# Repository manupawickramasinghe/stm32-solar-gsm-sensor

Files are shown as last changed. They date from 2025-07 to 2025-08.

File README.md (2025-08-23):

# stm32-solar-gsm-sensor
Firmware and hardware guide for an open-source, solar-powered agricultural sensor system based on the STM32 "Blue Pill" and a SIM800L GSM module.

This project is designed for remote environmental monitoring. It periodically reads data from multiple sensors based on DIP switch configuration, aggregates the data, and sends a summary report via SMS to a predefined list of phone numbers. It is optimized for low-power operation, making it suitable for solar or battery-powered deployments.

## Features
- **Multi-Sensor Support with DIP Switch Selection**: 
  - DHT11 temperature and humidity sensor
  - DS18B20 waterproof temperature sensor
  - FC-28 soil moisture sensor
  - MQ2 gas sensor
  - 4-position DIP switch for enabling/disabling individual sensors

- **GSM Connectivity**: Uses a SIM800L module to connect to the cellular network for sending and receiving SMS messages.

- **Periodic Data Reporting**: The device wakes up every 5 minutes to take sensor readings from enabled sensors only.

- **Dynamic SMS Content**: SMS reports include only data from sensors that are enabled via DIP switches. If no sensors are enabled, only timestamp is sent.

- **Averaged Data SMS**: After a set number of readings (e.g., 12 readings over 60 minutes), it calculates the average sensor values and sends a consolidated report via SMS.

- **Multi-Recipient SMS**: Sends the report to a configurable list of multiple phone numbers.

- **Network Timestamp**: Fetches the current date and time from the cellular network and includes it in every SMS report for accurate logging.

- **Persistent Counter**: Uses Flash memory emulation (since the STM32F103C8T6 does not have built-in EEPROM) to save its reading counter, ensuring it can resume its cycle even after a power loss or reset.

- **Remote Control via SMS**: Comprehensive SMS command system for remote configuration and monitoring.

## Hardware Requirements
- **Microcontroller**: STM32F103C8T6 "Blue Pill" board.

- **GSM Module**: SIM800L module (ensure it comes with a spring antenna and a valid 2G SIM card).

- **DIP Switch**: 4-position DIP switch for sensor selection.

- **Sensors**:
  - DHT11 Temperature and Humidity Sensor (Pin: PB1)
  - DS18B20 Waterproof Temperature Sensor (Pin: PB0) with 4.7kΩ pull-up resistor
  - FC-28 Soil Moisture Sensor (Analog Pin: PA1)
  - MQ2 Gas Sensor (Analog Pin: PA4)

- **Pin Assignments for DIP Switches**:
  - DIP Switch 1 (DHT11): PC13
  - DIP Switch 2 (DS18B20): PC14  
  - DIP Switch 3 (Soil Moisture): PC15
  - DIP Switch 4 (MQ2 Gas): PB12

- **Programmer**: FTDI FT232RL USB-to-Serial adapter for flashing the firmware.

- **Power Supply**:
  - A stable power source for the SIM800L is critical. A 3.7V LiPo battery or a dedicated buck converter capable of supplying at least 2A peak current is highly recommended. Powering the SIM800L directly from the Blue Pill's 3.3V pin will cause instability.

## Software & Setup (Arduino IDE)
This project is built using the Arduino IDE with the official STM32 core.

1. **Install Arduino IDE**
   If you don't have it, download and install the latest version of the Arduino IDE.

2. **Install STM32 Board Support**
   Open the Arduino IDE.

   Go to `File > Preferences`.

   In the "Additional boards manager URLs" field, paste the following URL:

   ```
   https://github.com/stm32duino/BoardManagerFiles/raw/main/package_stmicroelectronics_index.json
   ```

   Go to `Tools > Board > Boards Manager...`.

   Search for "STM32 MCU based boards" and install the package by STMicroelectronics.

3. **Install Required Libraries**
   You need to install three libraries for the sensors.

   Go to `Tools > Manage Libraries...`.

   Search for and install each of the following libraries:

   - DHT sensor library by Adafruit

   - OneWire by Paul Stoffregen

   - DallasTemperature by Miles Burton

4. **Configure the Code**
   Open the `.ino` sketch file in the Arduino IDE.

   Modify the `phoneNumbers` array to include the recipient phone numbers you want to send the SMS reports to. Make sure to use the international format (e.g., +94...).

   ```cpp
   String phoneNumbers[] = {"+94719593248", "+94719751003"};
   ```

## Flashing the Firmware (Manual Upload)
Since this project uses an FTDI adapter, you cannot use the standard "Upload" button in the Arduino IDE. You must compile the binary and flash it manually using a command-line tool.

### Step 1: Compile and Export the Binary
In the Arduino IDE, select the correct board settings:

- `Tools > Board: "STM32 MCU based boards" > "Generic STM32F1 series"`

- `Tools > Board part number: "Bluepill F103C8"`

- `Tools > Upload method: "STM32CubeProgrammer (Serial)"`

Go to `Sketch > Export compiled Binary`. This will compile your code and create a `.hex` and `.bin` file in the sketch folder.

### Step 2: Install stm32flash
This is a lightweight, reliable tool for flashing STM32 devices via UART.

Open a terminal on your Linux machine and run:

```bash
sudo apt update
sudo apt install stm32flash
```

### Step 3: Set Up Hardware for Flashing
This is the most critical part. You must put the STM32 into its hardware bootloader mode.

- **Set Jumpers**:

  - Set the `BOOT0` jumper to the '1' position (HIGH).

  - Set the `BOOT1` jumper to the '0' position (LOW).

- **Wire the FTDI Adapter**:

  - FTDI GND -> STM32 GND

  - FTDI TX -> STM32 PA10 (RX1)

  - FTDI RX -> STM32 PA9 (TX1)

- **Connect and Reset**: Connect the FTDI adapter to your computer. Now, press the RESET button on the Blue Pill board. The board is now waiting for programming commands.

### Step 4: Fix Serial Port Permissions (One-Time Setup)
On Linux, your user needs permission to access serial devices.

Add your user to the dialout group:

```bash
sudo usermod -a -G dialout $USER
```

IMPORTANT: For this change to take effect, you must log out and log back in or reboot your computer.

### Step 5: Flash the Firmware
Open a terminal and navigate to your Arduino sketch directory where the `.bin` file was exported.

Run the `stm32flash` command:

```bash
stm32flash -b 115200 -w YourSketchName.ino.bin -v -g 0x0 /dev/ttyUSB0
```

- `-b 115200`: Sets the baud rate for reliable communication.

- `-w YourSketchName.ino.bin`: Specifies the binary file to write.

- `-v`: Verifies the flash after writing.

- `-g 0x0`: Starts execution from the beginning of the flash memory after programming.

- `/dev/ttyUSB0`: The serial port of your FTDI adapter.

### Step 6: Run the Application
Disconnect the power.

Set the `BOOT0` jumper back to the '0' position.

Reconnect power or press the RESET button.

The board will now boot into your application. You can open the Arduino IDE's Serial Monitor at 9600 baud to see the debug output.

## Code Explanation
- **Configuration (`#define`)**: All hardware pins, timing delays, and operational thresholds are defined at the top of the file for easy configuration.

- **setup()**: This function runs once on startup. It initializes the serial ports for debugging, starts the DHT and DS18B20 sensors, and crucially, initializes the SIM800L module with a series of AT commands to prepare it for sending SMS. It also reads the last known `smsCounter` value from the EEPROM.

- **loop()**: This is the main operational cycle.

  - It first ensures the GSM module is initialized and ready.

  - It reads the current temperature and humidity from both sensors.

  - The readings are added to summing variables (`dhtHumSum`, `dhtTempSum`, etc.).

  - A counter (`smsCounter`) is incremented and saved to the EEPROM.

  - It checks if `smsCounter` has reached the `SMS_SEND_THRESHOLD` (e.g., 12).

  - If the threshold is met, it calculates the averages, fetches a network timestamp, formats the SMS message, and sends it to all phone numbers in the `phoneNumbers` array.

  - Finally, it resets the summing variables and the `smsCounter` back to zero and waits for 5 minutes (`MAIN_LOOP_CYCLE_DELAY`) before starting the next cycle.

- **GSM Helper Functions**: Functions like `sendSMS()`, `getGsmTimestamp()`, and `handleSim800lInput()` abstract the complexity of communicating with the SIM800L module.

## DIP Switch Configuration
The system uses a 5-position DIP switch to enable/disable individual sensors and MQTT publishing:

- **DIP Switch 1 (PC13)**: DHT11 Temperature & Humidity Sensor
- **DIP Switch 2 (PC14)**: DS18B20 Waterproof Temperature Sensor  
- **DIP Switch 3 (PC15)**: FC-28 Soil Moisture Sensor
- **DIP Switch 4 (PB12)**: MQ2 Gas Sensor
- **DIP Switch 5 (PB13)**: MQTT Publishing to test.mosquitto.org

**Switch Logic**: 
- Switch DOWN (pulled to ground) = Feature ENABLED
- Switch UP (pulled high) = Feature DISABLED

**Important**: The system reads DIP switches only during startup/boot. To change sensor or MQTT configuration, modify the DIP switches and restart the system. Only enabled sensors are read and included in SMS reports. If MQTT is enabled, data will be published to test.mosquitto.org after SMS transmission.

## SMS Commands
The system supports remote configuration and monitoring via SMS commands. Send these commands to the SIM card phone number:

### Configuration Commands
- **`NUMSETA +1234567890`**: Set phone number A
- **`NUMSETB +1234567890`**: Set phone number B  
- **`NUMSETC +1234567890`**: Set phone number C
- **`SETID 12345`**: Set customer ID (max 9 characters)

### Status Commands
- **`STATUS`**: Get current configuration, enabled sensors, and MQTT status
- **`TEST`**: Simple connectivity test
- **`SENSOR`**: Get current real-time sensor readings from enabled sensors
- **`MQTT`**: Test MQTT publishing (if MQTT enabled)

### Example SMS Responses
- **STATUS**: `ID:12345 A:+94719593248 B:+94719751003 C:+94768378406 Sensors: DHT DS18B20 SOIL MQTT`
- **SENSOR**: `ID:12345 Current: DHT H:65.2% T:28.4C; DS18B20:27.8C; Soil:45.3%;`
- **MQTT**: `ID:12345 MQTT test publish initiated`

## MQTT Integration
When the MQTT DIP switch is enabled (DIP Switch 5), the system will:

1. **Automatic Publishing**: After sending SMS data, automatically publish sensor data to MQTT
2. **MQTT Broker**: Uses test.mosquitto.org on port 1883 (public test broker)
3. **Topic Structure**: `sensors/stm32/{customer_id}`
4. **Data Format**: JSON payload with sensor readings and metadata
5. **Manual Testing**: Use `MQTT` SMS command to test publishing

### MQTT Data Example
```json
{
  "customer_id": "FARM01",
  "timestamp": "2025-08-03 14:30:15",
  "dht_humidity": 65.2,
  "dht_temperature": 28.4,
  "ds18b20_temperature": 27.8,
  "soil_moisture": 45.3,
  "gas_level": 12.1,
  "reading_count": 12
}
```

All configurations are saved to EEPROM and persist across power cycles.

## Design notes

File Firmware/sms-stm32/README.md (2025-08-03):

# STM32 Solar GSM Sensor System

A non-blocking, state-machine-based environmental monitoring system using STM32 Blue Pill with DHT11, DS18B20 sensors, and SIM800L GSM module for remote SMS notifications and configuration.

## 🌟 Features

- **Dual Temperature Sensors**: DHT11 (humidity + temperature) and DS18B20 (precision temperature)
- **SMS Notifications**: Automatic periodic sensor data reports via SMS
- **Remote Configuration**: Change phone numbers and customer ID via SMS commands
- **Non-blocking Architecture**: Fully asynchronous operation using state machines
- **EEPROM Storage**: Persistent configuration storage
- **Timestamp Integration**: GSM network time for accurate data logging
- **Multiple Recipients**: Send data to up to 3 phone numbers simultaneously

## 📱 SMS Commands

| Command | Description | Example |
|---|---|---|
| `STATUS` | Get current configuration | `STATUS` |
| `TEST` | Test system response | `TEST` |
| `NUMSETA +1234567890` | Update phone number A | `NUMSETA +94712345678` |
| `NUMSETB +1234567890` | Update phone number B | `NUMSETB +94712345678` |
| `NUMSETC +1234567890` | Update phone number C | `NUMSETC +94712345678` |
| `SETID CUSTOMER1` | Set customer ID (max 9 chars) | `SETID FARM01` |

### Example SMS Responses
```
Send: STATUS
Receive: 2025-08-02 14:30:15 - ID:00000 A:+94719593248 B:+94719751003 C:+94768378406

Send: NUMSETB +94716223703
Receive: 2025-08-02 14:30:25 - ID:00000 NUMSETB updated to +94716223703

Send: SETID FARM01
Receive: 2025-08-02 14:30:35 - ID:FARM01 Customer ID updated to FARM01
```

## 🔧 Hardware Configuration

### Pin Connections
```
STM32 Blue Pill Connections:
├── DHT11 Sensor
│   └── Data Pin: PB1
├── DS18B20 Sensor
│   └── Data Pin: PB0 (with 4.7kΩ pull-up resistor)
├── SIM800L GSM Module
│   ├── RX: PA3 (STM32 TX → SIM800L RX)
│   ├── TX: PA2 (STM32 RX ← SIM800L TX)
│   └── Baud Rate: 9600
└── Power: 3.3V/5V (depending on module requirements)
```

### Required Components
- STM32 Blue Pill (STM32F103C8T6)
- DHT11 Temperature & Humidity Sensor
- DS18B20 Digital Temperature Sensor
- 4.7kΩ resistor (for DS18B20 pull-up)
- SIM800L GSM/GPRS Module
- SIM card with SMS capability
- Power supply (suitable for GSM module)

## 📊 System Operation

### Automatic Data Collection
- **Reading Cycle**: Every 5 minutes (300,000ms)
- **SMS Threshold**: Sends SMS after 12 readings (60 minutes of data)
- **Data Averaging**: Calculates average values over the collection period
- **Auto Reset**: Counters and averages reset after SMS transmission

### Example Sensor Data SMS
```
2025-08-02 21:10:59 - ID:FARM01 60min Avg - DHT H:65.2% T:28.5C; DS18B20 T:27.8C
```

## 🏗️ Software Architecture

### State Machine Design
The system uses multiple state machines for non-blocking operation:

#### 1. Main Sensor State Machine
```
STATE_IDLE → STATE_WAIT_DHT → STATE_READ_DHT → 
STATE_WAIT_DS18B20 → STATE_READ_DS18B20 → 
STATE_PROCESS_DATA → STATE_IDLE
```

#### 2. GSM Initialization State Machine
```
GSM_INIT_START → GSM_INIT_BOOT_DELAY → 
GSM_INIT_ECHO_OFF_WAIT → GSM_INIT_AT_TEST → 
GSM_INIT_AT_TEST_WAIT → ... → GSM_INIT_COMPLETE
```

#### 3. SMS Operation State Machine
```
SMS_IDLE → SMS_READ_WAIT → SMS_DELETE_WAIT
SMS_IDLE → SMS_SEND_CMD_WAIT → SMS_SEND_DATA_WAIT → SMS_SEND_END_WAIT
```

### Key Functions

#### Core Loop Functions
- `loop()`: Main system loop with state machine coordination
- `updateGsmInitialization()`: Non-blocking GSM module setup
- `updateSmsOperations()`: Handles SMS read/send/delete operations
- `updateSmsProcessing()`: Processes incoming SMS commands
- `handleSim800lInput()`: Manages incoming GSM module data

#### SMS Command Processing
- `extractSmsContentAndSender()`: Parses SMS content and sender info
- `parseAndExecuteSmsCommand()`: Executes SMS commands and generates responses
- `sendSMS()`: Sends SMS with timestamp to specified number

#### Configuration Management
- `loadConfigFromEEPROM()`: Loads saved configuration on startup
- `savePhoneNumberToEEPROM()`: Saves phone numbers to EEPROM
- `saveCustomerIDToEEPROM()`: Saves customer ID to EEPROM

## 💾 EEPROM Memory Map

| Address | Size | Description |
|---|---|---|
| 0 | 4 bytes | SMS Counter |
| 4-23 | 20 bytes | Phone Number A |
| 24-43 | 20 bytes | Phone Number B |
| 44-63 | 20 bytes | Phone Number C |
| 64-73 | 10 bytes | Customer ID |
| 74 | 1 byte | Initialization Flag |

## ⚙️ Configuration Parameters

### Timing Configuration
```cpp
#define MAIN_LOOP_CYCLE_DELAY 300000    // 5 minutes between readings
#define SMS_SEND_THRESHOLD 12           // Send SMS after 12 readings
#define DHT_READ_PRE_DELAY 2000         // 2 second DHT stabilization
#define DS18B20_READ_PRE_DELAY 100      // 100ms DS18B20 delay
```

### GSM Timeouts
```cpp
#define SIM800L_BOOTUP_DELAY 3000       // 3 second boot delay
#define SIM800L_SMS_SEND_END_DELAY 10000 // 10 second SMS send timeout
#define SIM800L_RESPONSE_READ_TIMEOUT 1000 // 1 second response timeout
```

### Default Configuration
```cpp
Phone Numbers: +94719593248, +94719751003, +94768378406
Customer ID: 00000
Baud Rates: Debug=9600, SIM800L=9600
```

## 🔄 Key Improvements Over Traditional Arduino Code

### 1. **Non-blocking Operation**
- No `delay()` calls that block execution
- Multiple operations can run simultaneously
- System remains responsive during long operations

### 2. **State Machine Architecture**
- Predictable state transitions
- Easy debugging and maintenance
- Robust error recovery

### 3. **Timeout Protection**
- 30-second timeouts prevent infinite loops
- Automatic recovery from stuck operations
- Circuit breaker pattern implementation

### 4. **Memory Management**
- Efficient EEPROM usage
- Persistent configuration storage
- String buffer management

## 🚀 Getting Started

### 1. Hardware Setup
1. Connect sensors and GSM module as per pin configuration
2. Insert activated SIM card into SIM800L module
3. Ensure adequate power supply for GSM module

### 2. Software Upload
1. Install required libraries:
   - DHT sensor library
   - OneWire library
   - DallasTemperature library
2. Configure pin assignments if different from defaults
3. Upload code to STM32 Blue Pill

### 3. Initial Configuration
1. Monitor serial output for system initialization
2. Send `STATUS` SMS to check current configuration
3. Update phone numbers using `NUMSETA/B/C` commands
4. Set customer ID using `SETID` command

### 4. Operation Verification
1. Send `TEST` SMS to verify system response
2. Wait for automatic sensor data SMS (60 minutes)
3. Monitor serial output for debugging information

## 🐛 Troubleshooting

### Common Issues

#### SMS Not Received
- Check SIM card balance and SMS capability
- Verify GSM network registration
- Check antenna connection
- Monitor serial output for GSM initialization errors

#### Sensor Reading Issues
- Verify sensor connections and power
- Check pull-up resistor for DS18B20 (4.7kΩ)
- Monitor serial output for sensor readings

#### SMS Commands Not Working
- Ensure exact command format (case-insensitive)
- Check SMS content extraction in serial monitor
- Verify sender number format

### Debug Output
The system provides comprehensive debug information:
```
SIM_RECV_URC: [GSM module responses]
=== Raw SMS Response === [SMS content parsing]
Extracted SMS from: [sender info]
Processing SMS command: [command processing]
```

## 📈 Performance Characteristics

- **Response Time**: SMS commands processed within 10-15 seconds
- **Data Accuracy**: ±0.5°C temperature, ±2% humidity
- **Power Consumption**: Optimized for battery operation
- **Memory Usage**: ~75% of STM32F103C8T6 flash memory
- **Reliability**: 30-second timeout protection on all operations

## 🔮 Future Enhancements

- Solar panel voltage monitoring
- Battery level reporting
- Data logging to SD card
- Web dashboard integration
- Multiple sensor support
- GPS location tracking

## 📄 License

This project is open source. Feel free to modify and distribute according to your needs.

---

**Note**: This system is designed for agricultural and environmental monitoring applications where reliable, remote data collection is essential.

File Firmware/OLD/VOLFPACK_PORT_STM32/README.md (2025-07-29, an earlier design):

\# \*\*STM32 Low-Power Soil Moisture \& GSM Sensor\*\*

This document provides a complete guide to the hardware, software, and operation of the STM32-based low-power soil moisture sensor.

\## \*\*Project Overview\*\*

This project turns an STM32 "Blue Pill" board into a remote, battery-powered sensor node. Its primary function is to wake up periodically (e.g., once an hour), measure soil moisture, report the data to a Google Sheet via GPRS, send a status update via SMS, and then return to a deep sleep mode to conserve energy.

The system is designed for long-term, unattended deployment in agricultural or environmental monitoring scenarios.

\## \*\*Required Libraries \& Installation\*\*

This project depends on two key libraries from STMicroelectronics that are not always available in the Arduino Library Manager. You must install them manually from their GitHub repositories.

\### \*\*1\\. STM32RTC Library\*\*

\* \*\*Purpose:\*\* This library provides access to the STM32's built-in Real-Time Clock (RTC). The STM32LowPower library \*\*requires\*\* this to schedule wake-up alarms that pull the microcontroller out of deep sleep.  

\* \*\*GitHub Repository:\*\* \[https://github.com/stm32duino/STM32RTC](https://github.com/stm32duino/STM32RTC)

\### \*\*2\\. STM32LowPower Library\*\*

\* \*\*Purpose:\*\* This is the core library for power management. It allows you to put the STM32 into various low-power states, such as deepSleep(), which dramatically reduces energy consumption.  

\* \*\*GitHub Repository:\*\* \[https://github.com/stm32duino/STM32LowPower](https://github.com/stm32duino/STM32LowPower)

\### \*\*Installation Instructions (for both libraries)\*\*

1\. \*\*Download the Library:\*\*  

&nbsp;  \* Go to the GitHub repository page for the library.  

&nbsp;  \* Click the green \*\*\\< \\> Code\*\* button.  

&nbsp;  \* In the dropdown menu, click \*\*Download ZIP\*\*. This will save a file like STM32RTC-main.zip or STM32LowPower-main.zip to your computer.  

2\. \*\*Install in Arduino IDE:\*\*  

&nbsp;  \* Open the Arduino IDE.  

&nbsp;  \* Go to the menu \*\*Sketch \\> Include Library \\> Add .ZIP Library...\*\*.  

&nbsp;  \* Navigate to your Downloads folder and select the .zip file you just downloaded.  

&nbsp;  \* Click \*\*Open\*\*.

Repeat this process for both libraries.

\## \*\*Code Explanation\*\*

The firmware is designed around a single-shot, sleep-centric execution model. The device wakes up, runs the setup() function once, and then goes back into a deep sleep. The loop() function is intentionally empty.

\### \*\*Key Sections of the Code:\*\*

\* \*\*Configuration (\\#define and globals):\*\*  

&nbsp; \* DEBUG\\\_MODE: A critical flag. Set to 1 to enable Serial.print() messages for testing. Set to 0 for deployment to reduce the program size and save power.  

&nbsp; \* \*\*Pin Definitions:\*\* Sets which STM32 pins are used for the sensor and for controlling power to the GSM module.  

&nbsp; \* \*\*HardwareSerial:\*\* HardwareSerial Serial2(PA3, PA2); explicitly creates the Serial2 object for the SIM800L module, which is more robust than using software serial on an STM32.  

&nbsp; \* \*\*Network \& API:\*\* Stores the recipient phone numbers and the Google Apps Script URL for data upload.  

&nbsp; \* \*\*EEPROM Addresses:\*\* Defines where the last successful activation timestamp is stored in the microcontroller's non-volatile memory.  

\* \*\*setup() function:\*\*  

&nbsp; \* This acts as the main function every time the device wakes up from a reset or deep sleep.  

&nbsp; \* It initializes the LowPower library and configures the GPIO pins.  

&nbsp; \* It calls readLastActivation() to load the timestamp of the last successful run from EEPROM.  

&nbsp; \* It calls shouldPerformCycle() to decide if it's time to take a new reading.  

&nbsp; \* If the conditions are met, it calls performCycle() to do the main work.  

&nbsp; \* Finally, it calls enterSleepMode() to power down for the next cycle.  

\* \*\*shouldPerformCycle() function:\*\*  

&nbsp; \* This is the decision-making core.  

&nbsp; \* It briefly powers up the GSM module to get the current network time.  

&nbsp; \* It checks if the current time is within the first 5 minutes of a new hour.  

&nbsp; \* It compares the current hour and day to the timestamp stored in EEPROM to ensure it hasn't already performed a cycle for the current hour.  

&nbsp; \* It returns true (run the cycle) or false (go back to sleep).  

\* \*\*performCycle() function:\*\*  

&nbsp; \* Powers on the sensor and GSM module.  

&nbsp; \* Reads the analog value from the soil moisture sensor.  

&nbsp; \* Connects to the GPRS network.  

&nbsp; \* Formats a status message containing the timestamp, soil moisture percentage, and internet status.  

&nbsp; \* Sends the status message via SMS and uploads the data to the Google Sheet.  

&nbsp; \* Powers down the GSM module.  

\* \*\*enterSleepMode() function:\*\*  

&nbsp; \* Ensures all peripherals are powered down.  

&nbsp; \* Prints a final debug message if enabled.  

&nbsp; \* Calls LowPower.deepSleep(3600000); to put the STM32 into its lowest power state for 1 hour. The device will reset upon waking up, starting the setup() function again.  

\* \*\*EEPROM Functions (saveLastActivation, readLastActivation):\*\*  

&nbsp; \* These functions handle saving and retrieving the timestamp to the STM32's emulated EEPROM. This prevents the device from sending duplicate data if it unexpectedly resets.  

\* \*\*GSM Helper Functions (powerCycleGSM, connectToGPRS, sendSMS, sendGET, etc.):\*\*  

&nbsp; \* These are utility functions that manage the low-level AT command communication with the SIM800L module to perform tasks like connecting to the network, sending an SMS, or making an HTTP GET request.

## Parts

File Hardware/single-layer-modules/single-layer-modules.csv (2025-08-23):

Reference | Qty | Value | DNP | Exclude from BOM | Exclude from Board | Footprint | Datasheet
C1,C2,C3 | 3 | C_Polarized |  |  |  | Capacitor_THT:CP_Radial_D17.0mm_P7.50mm | ~
D1,D2 | 2 | 1N4448 |  |  |  | Diode_THT:D_DO-35_SOD27_P7.62mm_Horizontal | https://assets.nexperia.com/documents/data-sheet/1N4148_1N4448.pdf
J1 | 1 | Blue Pill - 1 |  |  |  | Connector_PinHeader_2.54mm:PinHeader_1x20_P2.54mm_Vertical | ~
J2 | 1 | Blue Pill - 2 |  |  |  | Connector_PinHeader_2.54mm:PinHeader_1x20_P2.54mm_Vertical | ~
J3 | 1 | SIM800L |  |  |  | Connector_PinSocket_2.54mm:PinSocket_1x07_P2.54mm_Vertical | ~
J4 | 1 | DS18B20 |  |  |  | Connector_PinSocket_2.54mm:PinSocket_1x03_P2.54mm_Vertical | ~
J5 | 1 | DHT11 |  |  |  | Connector_PinSocket_2.54mm:PinSocket_1x03_P2.54mm_Vertical | ~
J6 | 1 | FC-28 |  |  |  | Connector_PinSocket_2.54mm:PinSocket_1x03_P2.54mm_Vertical | ~
J7 | 1 | MQ-02 |  |  |  | Connector_PinSocket_2.54mm:PinSocket_1x03_P2.54mm_Vertical | ~
J8,J9,J10,J11 | 4 | Conn_01x01_Pin |  |  |  | Connector_PinSocket_2.54mm:PinSocket_1x01_P2.54mm_Vertical | ~
J12 | 1 | Conn_01x02_Socket |  |  |  | Connector_AMASS:AMASS_XT30UPB-M_1x02_P5.0mm_Vertical | ~
JP1 | 1 | SolderJumper_3_Bridged12 |  | Excluded from BOM |  | Connector_JST:JST_PH_S3B-PH-K_1x03_P2.00mm_Horizontal | ~
Q1 | 1 | IRF4905 |  |  |  | Package_TO_SOT_THT:TO-220-3_Vertical | http://www.infineon.com/dgdl/irf4905.pdf?fileId=5546d462533600a4015355e32165197c
Q2 | 1 | 2N3904 |  |  |  | Package_TO_SOT_THT:TO-92L_HandSolder | https://www.onsemi.com/pub/Collateral/2N3903-D.PDF
R1,R2,R3,R4,R5,R6,R7,R8,R9,R10,R11,R12,R13,R14,R15,R16,R17,R18,R19,R20,R21,R22,R23,R24 | 24 | R |  |  |  | Resistor_THT:R_Axial_DIN0411_L9.9mm_D3.6mm_P15.24mm_Horizontal | ~
SW1 | 1 | SW_DIP_x05 |  |  |  | Button_Switch_THT:SW_DIP_SPSTx05_Slide_9.78x14.88mm_W7.62mm_P2.54mm | ~
U1,U2 | 2 | LM358 |  |  |  | Package_DIP:DIP-8_W7.62mm_LongPads | http://www.ti.com/lit/ds/symlink/lm2904-n.pdf

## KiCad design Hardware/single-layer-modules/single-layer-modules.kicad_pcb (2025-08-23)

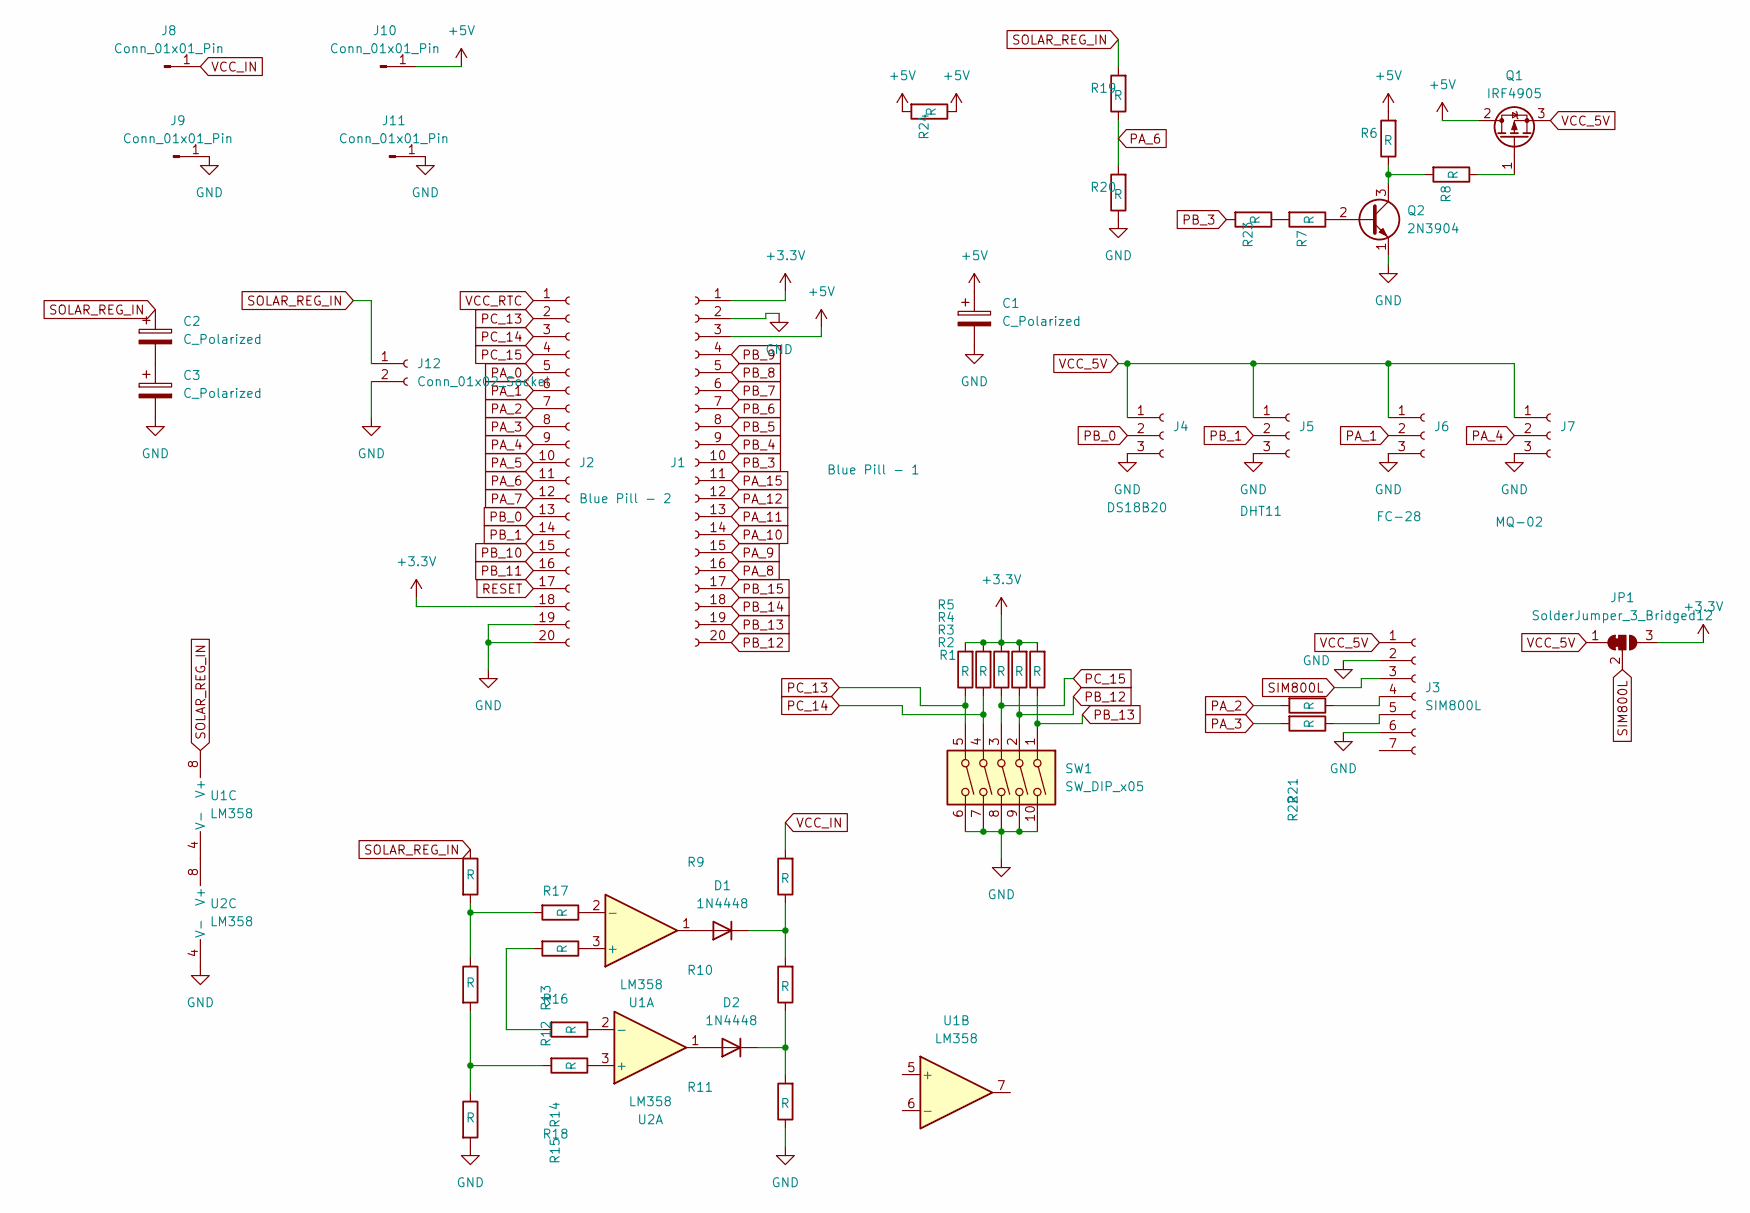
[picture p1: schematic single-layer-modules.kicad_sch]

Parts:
C1, C2, C3: C_Polarized; CP_Radial_D17.0mm_P7.50mm
D1, D2: 1N4448; D_DO-35_SOD27_P7.62mm_Horizontal
J1: Blue Pill - 1; PinHeader_1x20_P2.54mm_Vertical
J2: Blue Pill - 2; PinHeader_1x20_P2.54mm_Vertical
J3: SIM800L; PinSocket_1x07_P2.54mm_Vertical
J4: DS18B20; PinSocket_1x03_P2.54mm_Vertical
J5: DHT11; PinSocket_1x03_P2.54mm_Vertical
J6: FC-28; PinSocket_1x03_P2.54mm_Vertical
J7: MQ-02; PinSocket_1x03_P2.54mm_Vertical
J8, J9, J10, J11: Conn_01x01_Pin; PinSocket_1x01_P2.54mm_Vertical
J12: Conn_01x02_Socket; AMASS_XT30UPB-M_1x02_P5.0mm_Vertical
JP1: SolderJumper_3_Bridged12; JST_PH_S3B-PH-K_1x03_P2.00mm_Horizontal
Q1: IRF4905; TO-220-3_Vertical
Q2: 2N3904; TO-92L_HandSolder
R1, R2, R3, R4, R5, R6, R7, R8, R9, R10, R11, R12, R13, R14, R15, R16, R17, R18, R19, R20, R21, R22, R23, R24: R; R_Axial_DIN0411_L9.9mm_D3.6mm_P15.24mm_Horizontal
SW1: SW_DIP_x05; SW_DIP_SPSTx05_Slide_9.78x14.88mm_W7.62mm_P2.54mm
U1, U2: LM358; DIP-8_W7.62mm_LongPads

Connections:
+3.3V: J1.1, J2.18, JP1.3 (B), R1.2, R2.2, R3.2, R4.2, R5.2
+5V: C1.1, J1.3, J10.1, Q1.2 (D), R6.2, R24.1, R24.2
GND: C1.2, C3.2, J1.2, J2.19, J2.20, J3.2, J3.6, J4.3, J5.3, J6.3, J7.3, J8.3, J9.1, J11.1, J12.2, Q2.1 (E), R11.1, R18.2, R20.1, SW1.6, SW1.7, SW1.8, SW1.9, SW1.10, U2.4 (V-)
unnamed: C2.2, C3.1
unnamed: D1.2 (A), U1.1
unnamed: D1.1 (K), R9.1, R10.2
unnamed: D2.2 (A), U2.1
unnamed: D2.1 (K), R10.1, R11.2
unnamed: J3.4, R21.1
unnamed: J3.5, R22.1
unnamed: Q1.1 (G), R8.1
unnamed: Q2.2 (B), R7.1
unnamed: Q2.3 (C), R6.1, R8.2
unnamed: R12.2, R14.2
unnamed: R13.2, R16.1, R17.2
unnamed: R15.2, R16.2, R18.1
unnamed: R7.2, R23.1
unnamed: R12.1, U1.3 (+)
unnamed: R13.1, U1.2 (-)
unnamed: U1.4 (V-), U2.8 (V+)
unnamed: R15.1, U2.3 (+)
unnamed: R14.1, U2.2 (-)
PA_0: J2.5
PA_1: J2.6, J6.2
PA_2: J2.7, R21.2
PA_3: J2.8, R22.2
PA_4: J2.9, J7.2
PA_5: J2.10
PA_6: J2.11, R19.1, R20.2
PA_7: J2.12
PA_8: J1.16
PA_9: J1.15
PA_10: J1.14
PA_11: J1.13
PA_12: J1.12
PA_15: J1.11
PB_0: J2.13, J4.2
PB_1: J2.14, J5.2
PB_3: J1.10, R23.2
PB_4: J1.9
PB_5: J1.8
PB_6: J1.7
PB_7: J1.6
PB_8: J1.5
PB_9: J1.4
PB_10: J2.15
PB_11: J2.16
PB_12: J1.20, R2.1, SW1.2
PB_13: J1.19, R1.1, SW1.1
PB_14: J1.18
PB_15: J1.17
PC_13: J2.2, R5.1, SW1.5
PC_14: J2.3, R4.1, SW1.4
PC_15: J2.4, R3.1, SW1.3
RESET: J2.17
SIM800L: J3.3, JP1.2 (C)
SOLAR_REG_IN: C2.1, J12.1, R17.1, R19.2, U1.8 (V+)
VCC_RTC: J2.1

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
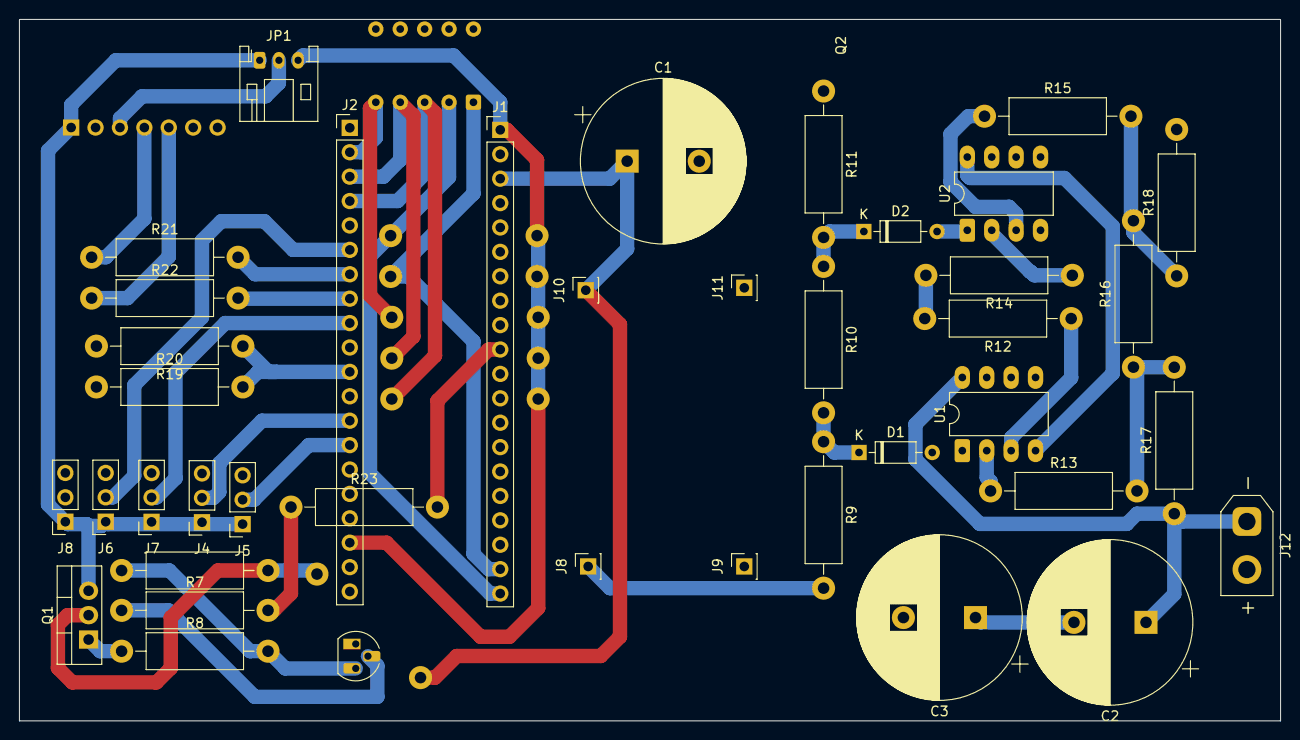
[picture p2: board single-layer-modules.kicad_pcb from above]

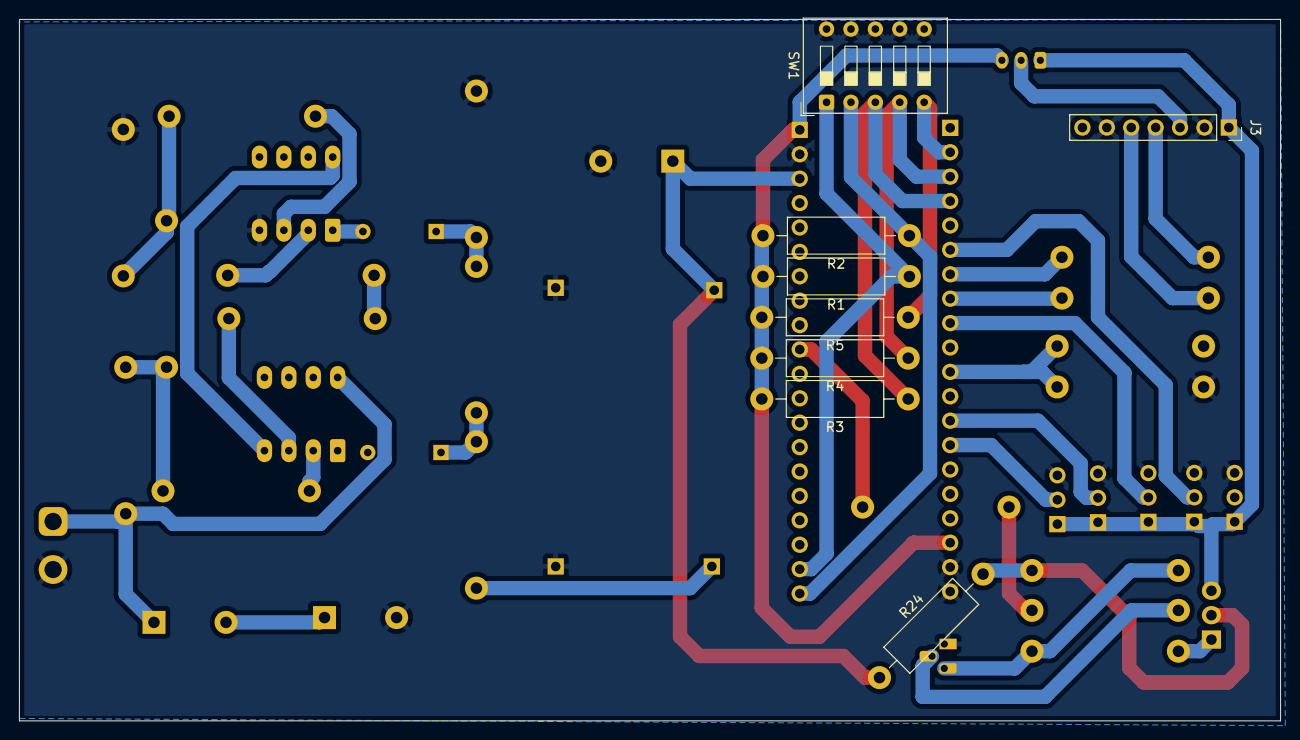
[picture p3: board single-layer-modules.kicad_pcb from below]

Board: 2 copper layers, 131.2 x 73.0 mm, 48 parts (8 on the bottom side), 39 nets.

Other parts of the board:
J8#2: Conn_01x01_Pin; PinSocket_1x01_P2.54mm_Vertical

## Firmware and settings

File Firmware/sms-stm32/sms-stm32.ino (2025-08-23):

#include "DHT.h"  // Main DHT sensor library
#include <OneWire.h>
#include <DallasTemperature.h>
#include <EEPROM.h> // Include the EEPROM library
#include <PubSubClient.h> // MQTT library for SIM800L

// --- Configuration for DHT Sensor ---
#define DHTPIN PB1     // Digital pin connected to the DHT sensor
#define DHTTYPE DHT11  // DHT 11

// --- Configuration for DS18B20 Sensor ---
#define ONE_WIRE_BUS PB0  // Data wire for DS18B20

// --- Configuration for Soil Moisture Sensor FC-28 ---
#define SOIL_MOISTURE_PIN PA1 // Analog pin for soil moisture sensor

// --- Configuration for MQ2 Gas Sensor ---
#define MQ2_GAS_PIN PA4 // Analog pin for MQ2 gas sensor

// --- Configuration for DIP Switches (Sensor Selection) ---
#define DIP_SWITCH_DHT11 PC13    // DIP switch 1 for DHT11 sensor
#define DIP_SWITCH_DS18B20 PC14  // DIP switch 2 for DS18B20 sensor
#define DIP_SWITCH_SOIL PC15     // DIP switch 3 for Soil Moisture sensor
#define DIP_SWITCH_MQ2 PB12      // DIP switch 4 for MQ2 Gas sensor
#define DIP_SWITCH_MQTT PB13     // DIP switch 5 for MQTT publishing

// --- Configuration for ADC Input ---
#define ADC_INPUT_PIN PA0 // Analog input pin for the trigger condition

// --- Configuration for GSM SIM800L Module ---
#define GSM_RX_PIN PA3                          // Bluepill RX from SIM800L TX (USART2_RX)
#define GSM_TX_PIN PA2                          // Bluepill TX to SIM800L RX (USART2_TX)
HardwareSerial sim800l(GSM_RX_PIN, GSM_TX_PIN); // Assumes this constructor works for your STM32 core for USART2
                                                // Standard way might be: HardwareSerial Serial2(PA3, PA2); and use Serial2

// --- Baud Rates ---
#define DEBUG_SERIAL_BAUDRATE 9600
#define SIM800L_BAUDRATE 9600

// --- GSM Module Delays & Timeouts ---
#define SIM800L_BOOTUP_DELAY 3000       // Increased delay after sim800l.begin()
#define SIM800L_GENERIC_CMD_DELAY 1000  // Increased general delay after AT commands
#define SIM800L_CREG_RESPONSE_DELAY 2000 // Increased delay for CREG? command response
#define SIM800L_TIMESTAMP_READ_DELAY 1000 // Increased delay for AT+CCLK? command response
#define SIM800L_SMS_READ_DELETE_DELAY 2000 // Increased delay for AT+CMGR/CMGD commands
#define SIM800L_SMS_SEND_CMD_DELAY 3000 // Increased delay after AT+CMGS command
#define SIM800L_SMS_SEND_DATA_DELAY 1000 // Increased delay after sending SMS message content
#define SIM800L_SMS_SEND_END_DELAY 10000 // Increased delay after sending CTRL+Z for SMS

// --- Sensor Reading Delays ---
#define DHT_READ_PRE_DELAY 2000         // Delay before reading DHT sensor
#define DS18B20_READ_PRE_DELAY 100      // Delay before reading DS18B20 sensor
#define SOIL_MOISTURE_READ_PRE_DELAY 100 // Delay before reading soil moisture sensor
#define MQ2_GAS_READ_PRE_DELAY 100      // Delay before reading MQ2 gas sensor

// --- Loop Control Delays ---
#define SERIAL_INIT_WAIT_DELAY 10       // Delay for Serial port initialization
#define MAIN_LOOP_CYCLE_DELAY 300000    // 5 minutes delay between full reading cycles
#define GSM_INIT_FAILURE_RETRY_DELAY 5000 // Delay before retrying GSM init after failure
#define ADC_IDLE_CHECK_DELAY 5000       // Delay when ADC condition is not met

// --- SIM800L Response Buffer Timeout ---
#define SIM800L_RESPONSE_READ_TIMEOUT 1000 // Timeout for reading SIM800L serial response

// --- MQTT Configuration ---
#define MQTT_SERVER "test.mosquitto.org"
#define MQTT_PORT 1883
#define MQTT_CLIENT_ID "STM32_Sensor_"
#define MQTT_TOPIC_PREFIX "zektopic/sensors/stm32/"
#define MQTT_CONNECT_TIMEOUT 10000    // 10 seconds for MQTT connection
#define MQTT_PUBLISH_TIMEOUT 5000     // 5 seconds for MQTT publish

// --- EEPROM Configuration ---
#define EEPROM_COUNTER_ADDR 0 // EEPROM address to store the counter
#define EEPROM_PHONE_A_ADDR 4 // EEPROM address for phone number A (20 bytes)
#define EEPROM_PHONE_B_ADDR 24 // EEPROM address for phone number B (20 bytes)
#define EEPROM_PHONE_C_ADDR 44 // EEPROM address for phone number C (20 bytes)
#define EEPROM_CUSTOMER_ID_ADDR 64 // EEPROM address for customer ID (10 bytes)
#define EEPROM_INIT_FLAG_ADDR 74 // EEPROM address for initialization flag
#define SMS_SEND_THRESHOLD 12 // Send SMS when counter reaches this value

// Phone number storage
#define MAX_PHONE_LENGTH 20
#define MAX_CUSTOMER_ID_LENGTH 10

// Array of phone numbers to send SMS to (will be loaded from EEPROM)
String phoneNumbers[] = {"+94719593248", "+94719751003", "+94768378406"};
const int NUM_PHONE_NUMBERS = 3;
String customerID = "00000"; // Default customer ID

// State machine states
enum SystemState {
    STATE_INIT,
    STATE_WAIT_DHT,
    STATE_READ_DHT,
    STATE_WAIT_DS18B20,
    STATE_READ_DS18B20,
    STATE_WAIT_SOIL_MOISTURE,
    STATE_READ_SOIL_MOISTURE,
    STATE_WAIT_MQ2_GAS,
    STATE_READ_MQ2_GAS,
    STATE_PROCESS_DATA,
    STATE_IDLE
};

// GSM initialization states
enum GsmInitState {
    GSM_INIT_START,
    GSM_INIT_BOOT_DELAY,
    GSM_INIT_ECHO_OFF,
    GSM_INIT_ECHO_OFF_WAIT,
    GSM_INIT_AT_TEST,
    GSM_INIT_AT_TEST_WAIT,
    GSM_INIT_CPMS,
    GSM_INIT_CPMS_WAIT,
    GSM_INIT_CMGF,
    GSM_INIT_CMGF_WAIT,
    GSM_INIT_CNMI,
    GSM_INIT_CNMI_WAIT,
    GSM_INIT_CREG,
    GSM_INIT_CREG_WAIT,
    GSM_INIT_COMPLETE,
    GSM_INIT_FAILED
};

// SMS operation states
enum SmsOperationState {
    SMS_IDLE,
    SMS_READ_WAIT,
    SMS_DELETE_WAIT,
    SMS_SEND_CMD_WAIT,
    SMS_SEND_DATA_WAIT,
    SMS_SEND_END_WAIT
};

// SMS processing states
enum SmsProcessingState {
    SMS_PROC_IDLE,
    SMS_PROC_READING,
    SMS_PROC_PROCESSING,
    SMS_PROC_RESPONDING
};

// Timestamp operation state
enum TimestampState {
    TS_IDLE,
    TS_WAITING_RESPONSE
};

// MQTT operation states
enum MqttOperationState {
    MQTT_IDLE,
    MQTT_GPRS_ATTACH,
    MQTT_GPRS_ATTACH_WAIT,
    MQTT_SET_APN, // Added state for setting APN
    MQTT_SET_APN_WAIT, // Added state for waiting for APN response
    MQTT_ACTIVATE_GPRS, // Added state for activating GPRS connection
    MQTT_ACTIVATE_GPRS_WAIT, // Added state for waiting for GPRS activation response
    MQTT_TCP_CONNECT,
    MQTT_TCP_CONNECT_WAIT,
    MQTT_PUBLISH_DATA,
    MQTT_PUBLISH_WAIT,
    MQTT_DISCONNECT,
    MQTT_DISCONNECT_WAIT,
    MQTT_COMPLETE,
    MQTT_FAILED
};

// Variables for sensor averaging and timing
float dhtHumSum = 0, dhtTempSum = 0, ds18b20TempSum = 0;
float soilMoistureSum = 0, mq2GasSum = 0;
int readingCount = 0;
unsigned long lastSendTime = 0;
unsigned long lastStateChange = 0;    // Tracks the last state change time
unsigned long lastMainLoopTime = 0;   // Tracks the last main cycle completion
SystemState currentState = STATE_IDLE;

// DIP switch states (sensor enable/disable)
bool dhtEnabled = false;
bool ds18b20Enabled = false;
bool soilMoistureEnabled = false;
bool mq2GasEnabled = false;
bool mqttEnabled = false;

// GSM operation timing variables
GsmInitState gsmInitState = GSM_INIT_START;
unsigned long gsmInitTimestamp = 0;
SmsOperationState smsOpState = SMS_IDLE;
unsigned long smsOpTimestamp = 0;
int pendingSmsIndex = 0;
TimestampState tsState = TS_IDLE;
unsigned long tsTimestamp = 0;

// MQTT operation timing variables
MqttOperationState mqttOpState = MQTT_IDLE;
unsigned long mqttOpTimestamp = 0;
String pendingMqttData = "";
bool mqttPublishPending = false;

// SMS sending state variables
String pendingSmsMessage = "";
String pendingSmsNumber = "";
int currentPhoneIndex = 0;

// SMS command processing variables
SmsProcessingState smsProcessingState = SMS_PROC_IDLE;
String receivedSmsContent = "";
String senderNumber = "";
int processingSmsIndex = 0;
unsigned long smsProcessingTimeout = 0;
String fullSmsResponse = ""; // Buffer to capture complete SMS response

DHT dht(DHTPIN, DHTTYPE);

OneWire oneWire(ONE_WIRE_BUS);
DallasTemperature ds18b20Sensors(&oneWire);

String simResponseBuffer = "";  // Buffer for incoming SIM800L data
bool gsmIsInitializedAndReady = false; // Flag to track GSM module initialization status
int smsCounter = 0; // Counter for SMS sending

// Forward declarations for functions
void readSimResponse();
void handleSim800lInput();
void readSms(int messageIndex);
void deleteSms(int messageIndex);
void sendSMS(String message, String recipientNumber);
bool updateGsmInitialization();
void updateSmsOperations();
void updateTimestampOperation();
bool isTimestampReady();
void startTimestampRequest();
void startSmsRead(int messageIndex);
void startSmsDelete(int messageIndex);
void startSmsSend(String message, String recipientNumber);
void loadConfigFromEEPROM();
void savePhoneNumberToEEPROM(int index, String phoneNumber);
void saveCustomerIDToEEPROM(String id);
void processSmsCommand(String smsContent, String sender);
void updateSmsProcessing();
void parseAndExecuteSmsCommand(String command, String sender);
void extractSmsContentAndSender();
void updateMqttOperations();
void startMqttPublish(String jsonData);
String buildSensorJsonData();

// --- Non-blocking Timestamp Functions ---
void startTimestampRequest() {
  if (!gsmIsInitializedAndReady) {
    Serial.println(F("GSM not ready, cannot get timestamp."));
    tsState = TS_IDLE;
    return;
  }
  Serial.println(F("Attempting to get GSM timestamp..."));
  sim800l.println("AT+CCLK?"); // Command to query clock
  tsState = TS_WAITING_RESPONSE;
  tsTimestamp = millis();
}

bool isTimestampReady() {
  return tsState == TS_IDLE;
}

void updateTimestampOperation() {
  if (tsState == TS_WAITING_RESPONSE) {
    if (millis() - tsTimestamp >= SIM800L_TIMESTAMP_READ_DELAY) {
      readSimResponse();
      tsState = TS_IDLE;
    }
  }
}

String getGsmTimestamp() {
  if (!gsmIsInitializedAndReady) {
    Serial.println(F("GSM not ready, cannot get timestamp."));
    return "TS_ERR";
  }
  
  // Start the request if not already started
  if (tsState == TS_IDLE) {
    startTimestampRequest();
  }
  
  // Wait for completion (this makes it blocking for now, but allows other operations)
  while (tsState != TS_IDLE) {
    updateTimestampOperation();
  }

  int cclkIndex = simResponseBuffer.indexOf("+CCLK: \"");
  if (cclkIndex != -1) {
    int startIndex = cclkIndex + 8; 
    int endIndex = simResponseBuffer.indexOf("\"", startIndex);
    if (endIndex != -1) {
      String dateTimeGsm = simResponseBuffer.substring(startIndex, endIndex);
      if (dateTimeGsm.length() >= 17) { 
        String year = "20" + dateTimeGsm.substring(0, 2);
        String month = dateTimeGsm.substring(3, 5);
        String day = dateTimeGsm.substring(6, 8);
        String hour = dateTimeGsm.substring(9,11);
        String minute = dateTimeGsm.substring(12,14);
        String second = dateTimeGsm.substring(15,17);
        return year + "-" + month + "-" + day + " " + hour + ":" + minute + ":" + second;
      }
    }
  }
  Serial.println(F("Error parsing CCLK response or CCLK not found in buffer."));
  return "TS_ERR"; 
}

// --- EEPROM Configuration Functions ---
void loadConfigFromEEPROM() {
  // Check if EEPROM has been initialized
  if (EEPROM.read(EEPROM_INIT_FLAG_ADDR) != 0x55) {
    Serial.println(F("EEPROM not initialized, using defaults and saving them."));
    // Save default values to EEPROM
    savePhoneNumberToEEPROM(0, phoneNumbers[0]);
    savePhoneNumberToEEPROM(1, phoneNumbers[1]);
    savePhoneNumberToEEPROM(2, phoneNumbers[2]);
    saveCustomerIDToEEPROM(customerID);
    EEPROM.write(EEPROM_INIT_FLAG_ADDR, 0x55); // Mark as initialized
  } else {
    Serial.println(F("Loading configuration from EEPROM..."));
    // Load phone numbers
    for (int i = 0; i < NUM_PHONE_NUMBERS; i++) {
      phoneNumbers[i] = "";
      int addr = EEPROM_PHONE_A_ADDR + (i * MAX_PHONE_LENGTH);
      for (int j = 0; j < MAX_PHONE_LENGTH; j++) {
        char c = EEPROM.read(addr + j);
        if (c == 0 || c == 255) break; // End of string
        phoneNumbers[i] += c;
      }
    }
    
    // Load customer ID
    customerID = "";
    for (int i = 0; i < MAX_CUSTOMER_ID_LENGTH; i++) {
      char c = EEPROM.read(EEPROM_CUSTOMER_ID_ADDR + i);
      if (c == 0 || c == 255) break; // End of string
      customerID += c;
    }
  }
  
  Serial.println(F("Configuration loaded:"));
  Serial.print(F("Phone A: ")); Serial.println(phoneNumbers[0]);
  Serial.print(F("Phone B: ")); Serial.println(phoneNumbers[1]);
  Serial.print(F("Phone C: ")); Serial.println(phoneNumbers[2]);
  Serial.print(F("Customer ID: ")); Serial.println(customerID);
}

void savePhoneNumberToEEPROM(int index, String phoneNumber) {
  if (index < 0 || index >= NUM_PHONE_NUMBERS) return;
  
  int addr = EEPROM_PHONE_A_ADDR + (index * MAX_PHONE_LENGTH);
  phoneNumbers[index] = phoneNumber;
  
  // Clear the EEPROM area first
  for (int i = 0; i < MAX_PHONE_LENGTH; i++) {
    EEPROM.write(addr + i, 0);
  }
  
  // Write the new phone number
  for (int i = 0; i < phoneNumber.length() && i < MAX_PHONE_LENGTH - 1; i++) {
    EEPROM.write(addr + i, phoneNumber[i]);
  }
  
  Serial.print(F("Phone number ")); 
  Serial.print((char)('A' + index)); 
  Serial.print(F(" saved: ")); 
  Serial.println(phoneNumber);
}
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
void loop() {
    // Always update ongoing operations
    updateTimestampOperation();
    updateSmsOperations();
    updateSmsProcessing();
    updateMqttOperations();
    
    // Always check for incoming SMS messages
    handleSim800lInput();

    // Non-blocking GSM initialization
    if (!gsmIsInitializedAndReady) {
        gsmIsInitializedAndReady = updateGsmInitialization();
        if (!gsmIsInitializedAndReady && gsmInitState == GSM_INIT_FAILED) {
            static unsigned long lastGsmInitAttempt = 0;
            if (millis() - lastGsmInitAttempt >= GSM_INIT_FAILURE_RETRY_DELAY) {
                Serial.println(F("Retrying GSM module initialization..."));
                gsmInitState = GSM_INIT_START;
                lastGsmInitAttempt = millis();
            }
        }
        return; // Don't proceed with sensor operations until GSM is ready
    }

    // Main state machine for sensor readings and data processing
    unsigned long currentMillis = millis();
    float h, t, tempC_ds18b20;  // Declare variables outside of switch

    switch (currentState) {
        case STATE_IDLE:
            if (currentMillis - lastMainLoopTime >= MAIN_LOOP_CYCLE_DELAY) {
                currentState = STATE_WAIT_DHT;
                lastStateChange = currentMillis;
                Serial.println(F("Starting new reading cycle..."));
            }
            break;

        case STATE_WAIT_DHT:
            if (dhtEnabled && currentMillis - lastStateChange >= DHT_READ_PRE_DELAY) {
                currentState = STATE_READ_DHT;
                Serial.println(F("--- Reading DHT Sensor ---"));
            } else if (!dhtEnabled) {
                // Skip DHT if disabled, go to next sensor
                currentState = STATE_WAIT_DS18B20;
                lastStateChange = currentMillis;
            }
            break;

        case STATE_READ_DHT:
            if (dhtEnabled) {
                h = dht.readHumidity();
                t = dht.readTemperature();
                if (!isnan(h) && !isnan(t)) {
                    Serial.print(F("DHT - H:")); Serial.print(h); 
                    Serial.print(F("% T:")); Serial.print(t); Serial.println(F("C"));
                    dhtHumSum += h;
                    dhtTempSum += t;
                }
            }
            currentState = STATE_WAIT_DS18B20;
            lastStateChange = currentMillis;
            break;

        case STATE_WAIT_DS18B20:
            if (ds18b20Enabled && currentMillis - lastStateChange >= DS18B20_READ_PRE_DELAY) {
                currentState = STATE_READ_DS18B20;
                Serial.println(F("--- Reading DS18B20 Sensor ---"));
            } else if (!ds18b20Enabled) {
                // Skip DS18B20 if disabled, go to next sensor
                currentState = STATE_WAIT_SOIL_MOISTURE;
                lastStateChange = currentMillis;
            }
            break;

        case STATE_READ_DS18B20:
            if (ds18b20Enabled) {
                ds18b20Sensors.requestTemperatures();
                tempC_ds18b20 = ds18b20Sensors.getTempCByIndex(0);
                if (tempC_ds18b20 != DEVICE_DISCONNECTED_C && tempC_ds18b20 != 85.0) {
                    Serial.print(F("DS18B20 - T:")); 
                    Serial.print(tempC_ds18b20); Serial.println(F("C"));
                    ds18b20TempSum += tempC_ds18b20;
                }
            }
            currentState = STATE_WAIT_SOIL_MOISTURE;
            lastStateChange = currentMillis;
            break;

        case STATE_WAIT_SOIL_MOISTURE:
            if (soilMoistureEnabled && currentMillis - lastStateChange >= SOIL_MOISTURE_READ_PRE_DELAY) {
                currentState = STATE_READ_SOIL_MOISTURE;
                Serial.println(F("--- Reading Soil Moisture Sensor ---"));
            } else if (!soilMoistureEnabled) {
                // Skip soil moisture if disabled, go to next sensor
                currentState = STATE_WAIT_MQ2_GAS;
                lastStateChange = currentMillis;
            }
            break;

        case STATE_READ_SOIL_MOISTURE:
            if (soilMoistureEnabled) {
                int soilMoistureRaw = analogRead(SOIL_MOISTURE_PIN);
                // Convert to percentage (0-4095 ADC range for STM32, inverted for soil moisture)
                float soilMoisturePercent = map(soilMoistureRaw, 4095, 0, 0, 100);
                soilMoisturePercent = constrain(soilMoisturePercent, 0, 100);
                Serial.print(F("Soil Moisture - Raw:")); Serial.print(soilMoistureRaw);
                Serial.print(F(" %:")); Serial.print(soilMoisturePercent); Serial.println(F("%"));
                soilMoistureSum += soilMoisturePercent;
            }
            currentState = STATE_WAIT_MQ2_GAS;
            lastStateChange = currentMillis;
            break;

        case STATE_WAIT_MQ2_GAS:
            if (mq2GasEnabled && currentMillis - lastStateChange >= MQ2_GAS_READ_PRE_DELAY) {
                currentState = STATE_READ_MQ2_GAS;
                Serial.println(F("--- Reading MQ2 Gas Sensor ---"));
            } else if (!mq2GasEnabled) {
                // Skip MQ2 if disabled, go to process data
                currentState = STATE_PROCESS_DATA;
            }
            break;

        case STATE_READ_MQ2_GAS:
            if (mq2GasEnabled) {
                int mq2GasRaw = analogRead(MQ2_GAS_PIN);
                // Convert to a relative gas concentration value (0-4095 ADC range)
                float mq2GasValue = (mq2GasRaw / 4095.0) * 100.0; // Percentage of full scale
                Serial.print(F("MQ2 Gas - Raw:")); Serial.print(mq2GasRaw);
                Serial.print(F(" Level:")); Serial.print(mq2GasValue); Serial.println(F("%"));
                mq2GasSum += mq2GasValue;
            }
            currentState = STATE_PROCESS_DATA;
            break;

        case STATE_PROCESS_DATA:
            readingCount++;
            smsCounter++;
            EEPROM.write(EEPROM_COUNTER_ADDR, smsCounter);
            Serial.print(F("SMS Counter: ")); Serial.println(smsCounter);

            if (smsCounter >= SMS_SEND_THRESHOLD && readingCount > 0) {
                // Build dynamic SMS message based on enabled sensors
                String sensorDataSms = "ID:" + customerID + " 60min Avg - ";
                bool hasData = false;
                
                if (dhtEnabled) {
                    float avgHum = dhtHumSum / readingCount;
                    float avgDhtTemp = dhtTempSum / readingCount;
                    sensorDataSms += "DHT H:" + String(avgHum, 1) + "% T:" + String(avgDhtTemp, 1) + "C; ";
                    hasData = true;
                }
                
                if (ds18b20Enabled) {
                    float avgDs18b20Temp = ds18b20TempSum / readingCount;
                    sensorDataSms += "DS18B20 T:" + String(avgDs18b20Temp, 1) + "C; ";
                    hasData = true;
                }
                
                if (soilMoistureEnabled) {
                    float avgSoilMoisture = soilMoistureSum / readingCount;
                    sensorDataSms += "Soil:" + String(avgSoilMoisture, 1) + "%; ";
                    hasData = true;
                }
                
                if (mq2GasEnabled) {
                    float avgMq2Gas = mq2GasSum / readingCount;
                    sensorDataSms += "Gas:" + String(avgMq2Gas, 1) + "%; ";
                    hasData = true;
                }
                
                // If no sensors are enabled, just send timestamp
                if (!hasData) {
                    sensorDataSms = "ID:" + customerID + " No sensors enabled - Timestamp only";
                }
                
                Serial.println(F("--- Sending SMS with Sensor Data ---"));
                for (int i = 0; i < NUM_PHONE_NUMBERS; i++) {
                    sendSMS(sensorDataSms, phoneNumbers[i]);
                }
                
                // Start MQTT publishing if enabled
                if (mqttEnabled) {
                    Serial.println(F("--- Preparing MQTT Data Publishing ---"));
                    String jsonData = buildSensorJsonData();
                    startMqttPublish(jsonData);
                }
                
                // Reset averages and counter
                dhtHumSum = 0;
                dhtTempSum = 0;
                ds18b20TempSum = 0;
                soilMoistureSum = 0;
                mq2GasSum = 0;
                readingCount = 0;
                smsCounter = 0;
                EEPROM.write(EEPROM_COUNTER_ADDR, smsCounter);
                lastSendTime = currentMillis;
            }
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

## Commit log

2025-07-21 Refactor GSM module initialization and delay handling; replace magic numbers with defined constants for better readability and maintainability.
    [sms-stm32.ino]
2025-07-21 Add initial files for single-layer modules design
    - Created new KiCad PCB file: single-layer-modules.kicad_pcb
    - Added project settings and configurations in single-layer-modules.kicad_prl
    - Established board design parameters in single-layer-modules.kicad_pro
    - Introduced schematic file: single-layer-modules.kicad_sch
    - Added lock file for schematic: ~single-layer-modules.kicad_sch.lck
    - Included backup zip file for single-layer modules
    [2-layer-components.kicad_pcb, 2-layer-components.kicad_sch, single-layer-modules.kicad_pcb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]
2025-07-29 Refactor GSM module initialization and sensor reading logic; add timestamp to SMS messages
2025-07-29 Refactor code structure for improved readability and maintainability
    [single-layer-modules.kicad_pcb, single-layer-modules.kicad_sch]
2025-07-29 Refactor GSM module logic: implement EEPROM for SMS counter, remove ADC condition checks, and streamline initialization process.
2025-07-29 Update README.md: Clarify description of the sensor system and correct EEPROM usage details for persistent counter.
2025-07-29 Refactor main loop to implement state machine for sensor readings and data processing; remove ADC condition checks and streamline GSM initialization logic.
2025-07-29 Enhance Arduino CLI installation and library setup with verbose output and verification steps
2025-07-29 Update Arduino CLI configuration and installation steps for STM32 support
2025-07-29 Enhance STM32 core installation and library setup with verbose output and verification steps
2025-07-29 Refactor STM32 library installation steps for clarity and verification
2025-07-29 Update library installation commands for STM32 setup to use specific library names
2025-07-29 Add legacy STM32 and Arduino soil moisture firmware
    Added STM32-based and Arduino-based soil moisture sensor firmware, including source code, documentation, and VSCode configuration files. These files provide low-power sensor node implementations with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
2025-08-02 Enhance SMS functionality and response handling; increase delays for GSM commands and improve error handling for SMS sending
    [sms-stm32.ino]
2025-08-02 Enhance sensor support and configuration; add DIP switch functionality for enabling/disabling sensors, update README for multi-sensor details and SMS command instructions
2025-08-02 Update README to clarify DIP switch reading behavior; specify that sensor configuration changes require a system restart
2025-08-02 Add MQTT support and update DIP switch configuration; enhance README with MQTT details and commands
2025-08-12 Refactor MQTT GPRS setup and publish flow
    Added new states for APN and GPRS activation in the MQTT operation state machine. Improved the GPRS setup sequence, including explicit APN configuration and activation steps. Refactored MQTT publish logic to send topic and payload directly, relying on SIM800L's AT command handling for MQTT framing. Enhanced error handling and connection management during MQTT operations.
    [sms-stm32.ino]
2025-08-13 Add autosave and backup files for PCB project
    Added KiCad autosave and backup files for the single-layer-modules project, including .kicad_pcb, .kicad_sch, and backup zip archives. Updated main PCB and schematic files with recent changes. Lock f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
2025-08-23 Add New PCB
    [single-layer-modules-B_Cu.gbr, single-layer-modules-B_Mask.gbr, single-layer-modules-B_Paste.gbr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]
